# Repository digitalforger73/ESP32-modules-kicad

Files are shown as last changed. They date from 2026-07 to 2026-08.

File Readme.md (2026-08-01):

<h1 align="center">ESP32 Community Board Project</h1>

<p align="center">
A complete ESP32 reference design built with KiCad.
</p>

## Preview

### PCB

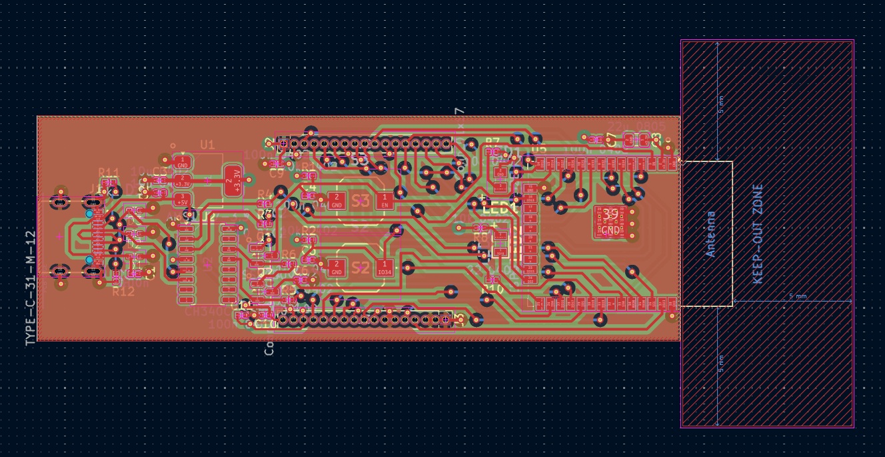
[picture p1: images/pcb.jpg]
ESP32 PCB


### Schematic

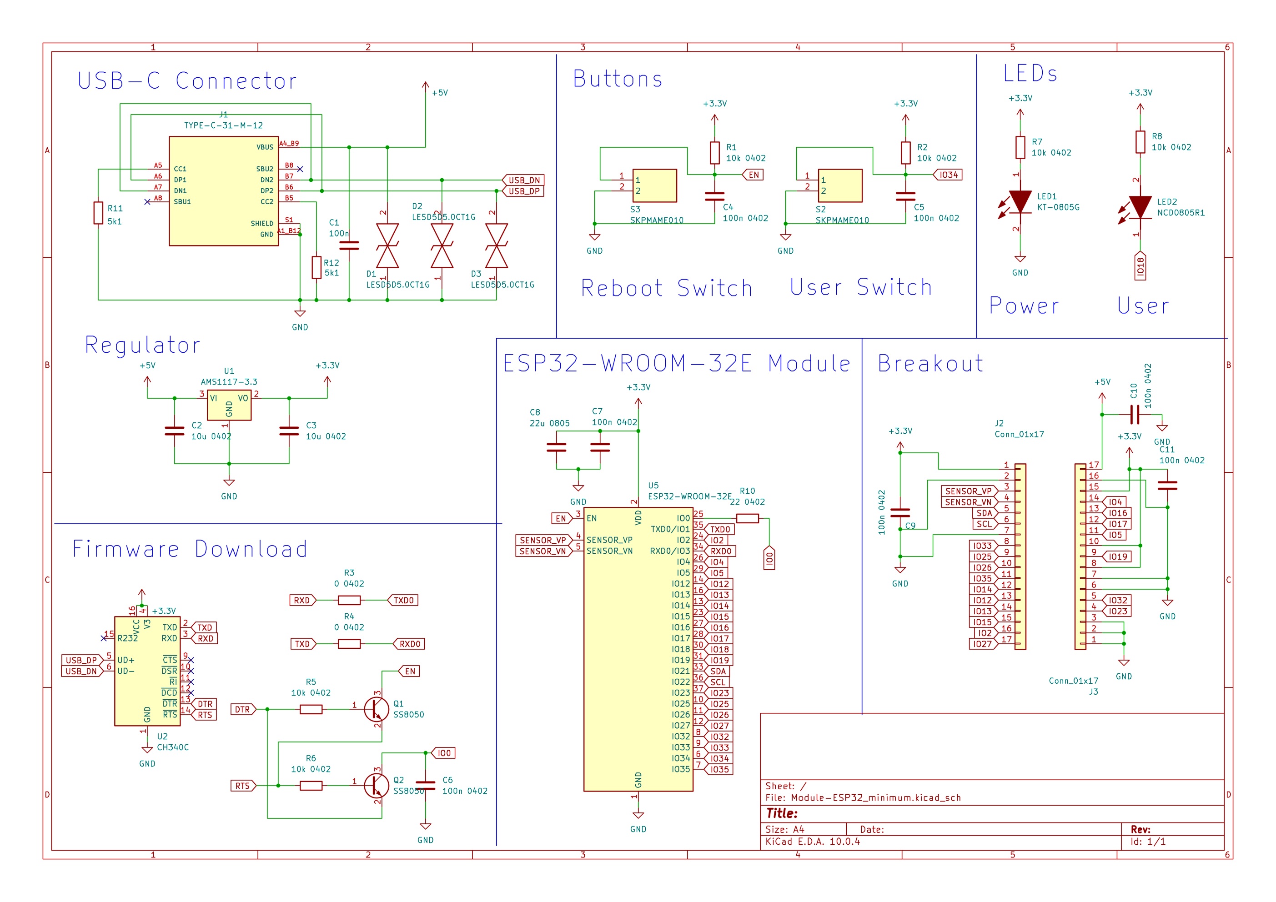
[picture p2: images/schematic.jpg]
ESP32 Schematic


An open community project for learning ESP32 hardware design with KiCad.

This repository contains a complete ESP32 development board designed in KiCad, intended for makers, students, and engineers who want to learn custom PCB design and build their own ESP32-based hardware.

<br>

## Professional Version - ESP32 Sensor Board

Need an ESP32 board with integrated sensors?

The **ESP32 Sensor Board** extends the Community Edition with a complete environmental sensing platform, making it suitable for IoT development, plant monitoring, and custom hardware projects.

### Professional Edition Includes

* SHTC3 temperature and humidity sensor
* Ambient light sensor
* Capacitive soil moisture sensor connector
* Complete KiCad project
* Schematic and PCB layout
* Symbol & footprint libraries
* BOM and Gerber files
* Component replacement guide
* Documentation

👉 **Professional Version on Gumroad**

[https://greentam.gumroad.com/](https://greentam.gumroad.com/?utm_source=github&utm_medium=readme&utm_campaign=community)

If you're looking for a solid starting point for your next ESP32 hardware project, the Professional Edition is designed to save development time while remaining fully customizable.

<br>

## Features

- ESP32-WROOM-32E
- USB Serial (CH340)
- 3.3V Power Regulator
- Reset / User Buttons
- A status LED / A user LED
- Programming Circuit
- Expansion Headers
- Symbols and Footprints on Components
- Component Replacement Guide

The project file contains the 4-layer substrate layout (front signal, 3.3 volt plane, ground plane, and back signal), and satisfies the pcb specification of the manufacturer, JLCPCB. 
You can give an order by uploading the gerber files, placement file, and bill-of-materials generated by the project files.
However, you can edit the files to match the specification of your chosen manufacturer.

<br>

## Who is this project for?

- ESP32 beginners
- Electronics hobbyists
- PCB designers
- Students
- Engineers learning KiCad
- Makers who want to build their own ESP32 board

<br>

## Community Edition

This repository contains the **Community Edition**.

The goal is to provide a minimal but practical ESP32 reference design that anyone can study and build.

<br>

## Documentation

- Component Replacement Guide
- Assembly Guide
- Hardware Documentation

<br>

## License

This project is licensed under the **Ippeul Community Hardware License (ICHL)**.

See the LICENSE file for details.

<br>

## Support

If you find this project useful, please consider:

- ⭐ Starring this repository
- Sharing it with other makers

<br><br>

<h1 align="center">KiCad를 이용한 ESP32 하드웨어 설계를 위한 ESP32 커뮤니티 보드</h1>

<p align="center">
KiCad로 디자인한 기본 ESP32 보드
</p>

<br>

이 저장소는 KiCad로 설계된 완전한 ESP32 개발 보드 프로젝트를 포함하고 있으며, 커스텀 PCB 설계를 배우고 자신만의 ESP32 기반 하드웨어를 제작하려는 메이커, 학생, 엔지니어를 위해 제작되었습니다.

<br>

## ESP32 센서 보드 (유료 버전)

센서가 통합된 ESP32 보드를 찾고 계신가요?

**ESP32 Sensor Board**는 Community Edition을 기반으로 온도·습도, 조도, 토양 수분 센서를 지원하도록 확장된 전문 KiCad 프로젝트입니다. IoT 기기, 식물 관리 시스템, 환경 모니터링 장치 등 다양한 하드웨어 개발에 바로 활용할 수 있습니다.

### ESP32 Sensor 구성

* SHTC3 온도·습도 센서
* 조도 센서
* 정전용량식 토양 수분 센서 연결 헤더
* 완전한 KiCad 프로젝트
* 회로도 및 PCB 설계
* 심볼 및 풋프린트 라이브러리
* BOM 및 Gerber 파일
* 부품 교체 가이드
* 프로젝트 문서

👉 Gumroad에서 다운로드:

[https://greentam.gumroad.com/](https://greentam.gumroad.com/?utm_source=github&utm_medium=readme&utm_campaign=community)

다음 ESP32 하드웨어 프로젝트를 보다 빠르게 시작하고 싶다면, ESP32 센서 보드는 검증된 회로와 PCB 설계를 바탕으로 개발 시간을 줄이면서도 자유롭게 수정하고 확장할 수 있는 기반을 제공합니다.

<br>

## ESP32 커뮤니티 보드 주요 기능 및 안내서
- ESP32-WROOM-32E
- USB 시리얼 인터페이스 (CH340)
- 3.3V 전압 레귤레이터
- Reset 버튼 / User 버튼
- 상태 표시 LED / 사용자 LED
- 펌웨어 다운로드 회로
- GPIO 확장 헤더
- 사용자 정의 심볼(Symbol) 및 풋프린트(Footprint)
- 대체 부품 가이드(Component Replacement Guide)

프로젝트 파일에는 4층 기판 구조가 포함되어 있습니다. 각 층은 전면 신호층, 3.3V 전원층, 접지층, 후면 신호층으로 구성되어 있으며, PCB 제조업체인 JLCPCB의 제작 사양을 충족합니다.
거버 파일, 부품 배치 파일, BOM(Bill of Materials)을 생성하고 업로드하여 바로 제작을 주문할 수 있습니다.
다만 선택한 PCB 제조업체의 제작 사양에 맞게 프로젝트 파일을 수정하여 사용할 수도 있습니다.

<br>

## 이 프로젝트는 누구를 위한 것인가요?
- ESP32를 처음 배우는 개발자
- 전자공학 취미 활동가
- PCB 설계자
- 학생
- KiCad를 배우는 엔지니어
- 자신만의 ESP32 보드를 제작하고 싶은 메이커

<br>

## 커뮤니티 버전
이 저장소에는 Community Edition이 포함되어 있습니다.

이 프로젝트의 목표는 누구나 학습하고 직접 제작할 수 있는 최소한의 기능을 갖춘 실용적인 ESP32 레퍼런스 디자인을 제공하는 것입니다.

<br>

## 라이선스
이 프로젝트는 Ippeul Community Hardware License (ICHL)에 따라 배포됩니다.
자세한 내용은 LICENSE 파일을 참고하시기 바랍니다.

<br>

## 서포트
프로젝트가 도움이 되었다면

이 프로젝트가 도움이 되었다면 다음과 같은 방법으로 응원해 주세요.

<br>

- ⭐ GitHub 저장소에 Star를 눌러 주세요.
- 다른 메이커와 개발자들에게 프로젝트를 공유해 주세요.

<br><br>

# ESP32 PCB 설계와 제작법을 제대로 배우고 싶다면

## KiCad로 만드는 나만의 센서 보드

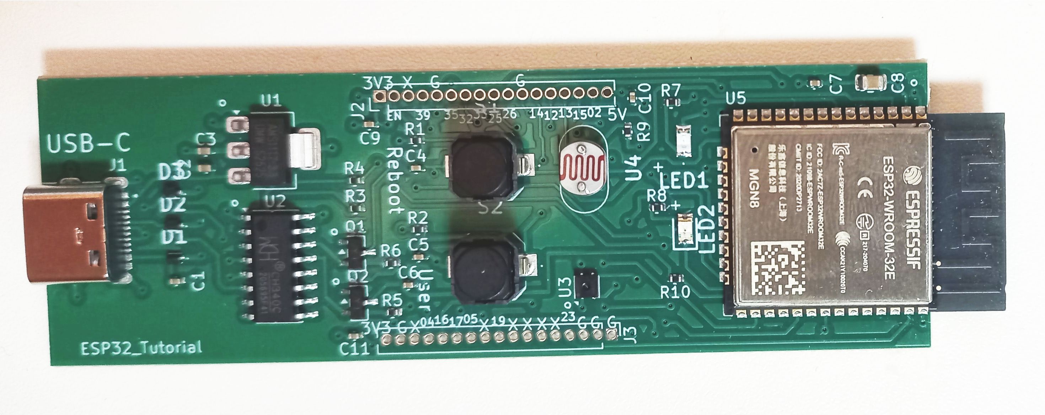
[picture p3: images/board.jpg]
ESP32 BOARD

(강의에서 제작하는 pcb)
<br>

ESP32 개발보드와 센서 모듈을 점퍼선으로 연결하는 데는 익숙하지만, 나만의 PCB를 설계하는 것은 막막하게 느껴질 수 있습니다.
<br>

이 강의에서는 실제 ESP32 센서 보드 프로젝트를 예제로 사용하여 다음 과정을 단계별로 배웁니다.
<br>

- ESP32 기본 회로 이해
- USB-C 전원 및 3.3V 전원 회로 설계
- CH340 기반 펌웨어 다운로드 회로
- 센서와 버튼·LED 연결
- KiCad 회로도 및 PCB 설계
- PCB 제조 파일 생성 및 주문
- ESP32 펌웨어 작성
- BLE와 Wi-Fi 통신 구현
<br>

강의를 마치면 개발보드를 사용하는 수준을 넘어, 원하는 기능을 갖춘 ESP32 PCB를 이해하고 직접 수정하거나 설계할 수 있습니다.
<br>

## 이런 분께 추천합니다
- ESP32 개발보드는 사용해봤지만 PCB 설계는 처음인 분
- KiCad를 실제 프로젝트를 통해 배우고 싶은 분
- 센서 기반 IoT 기기나 교육용 보드를 만들고 싶은 메이커
- 하드웨어와 펌웨어를 함께 이해하고 싶은 개발자
- 자신만의 IoT 시제품을 만들고 싶은 예비 창업자
<br>

강의에서는 수정 가능한 KiCad 프로젝트와 단계별 펌웨어를 함께 제공하여, 이후 다양한 ESP32 기반 프로젝트의 출발점으로 활용할 수 있습니다.
<br>

개발보드를 사용하는 사람에서, 자신의 보드를 설계하는 사람으로 한 단계 성장해 보세요.
<br>

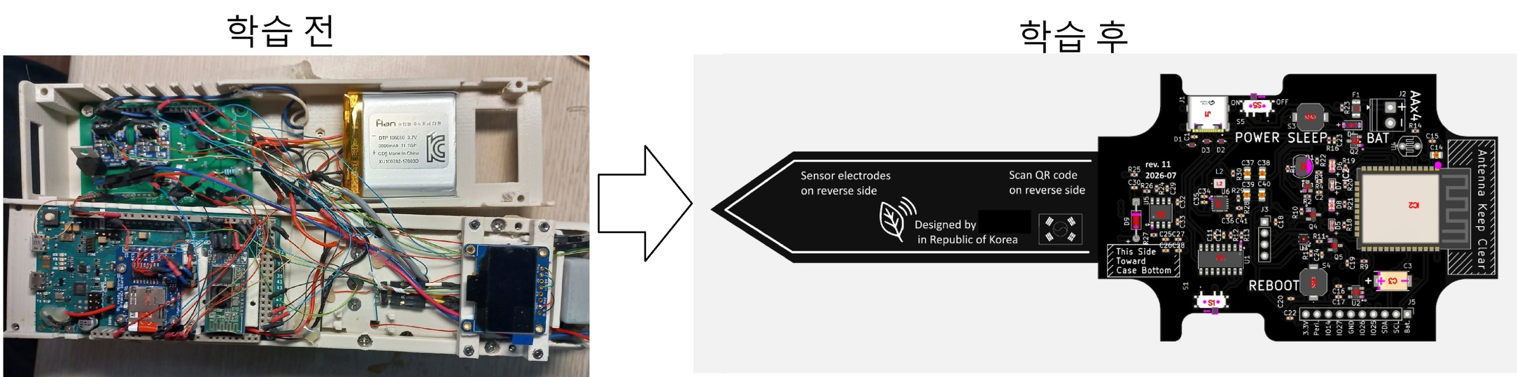
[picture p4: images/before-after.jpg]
ESP32 BEFORE_AFTER

(좌: 아두이노와 센서들이 각종 배선으로 연결된 시스템, 우: 센서와 ESP32가 일체화된 정돈된 커스텀 pcb)
<br>

## 강의 링크
https://inf.run/ZeYXg

<br>

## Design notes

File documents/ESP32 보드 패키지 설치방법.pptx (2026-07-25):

## ESP32 보드 패키지 설치방법

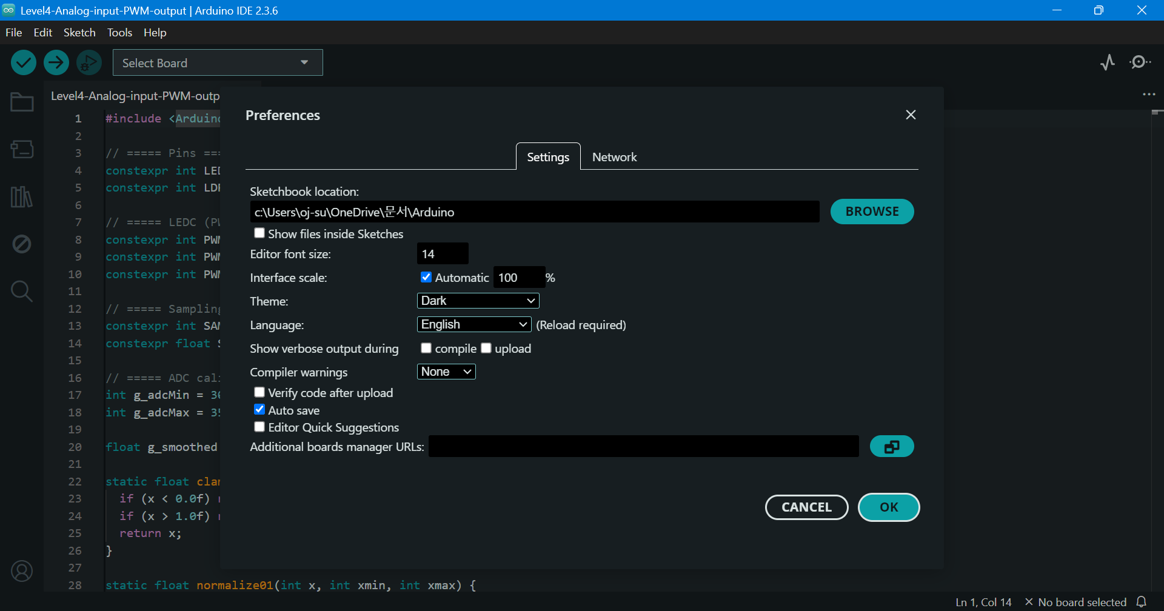
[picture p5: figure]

https://dl.espressif.com/dl/package_esp32_index.json

File → Preferences

## ESP32 보드 패키지 설치방법

Tools → Board → Boards Manager

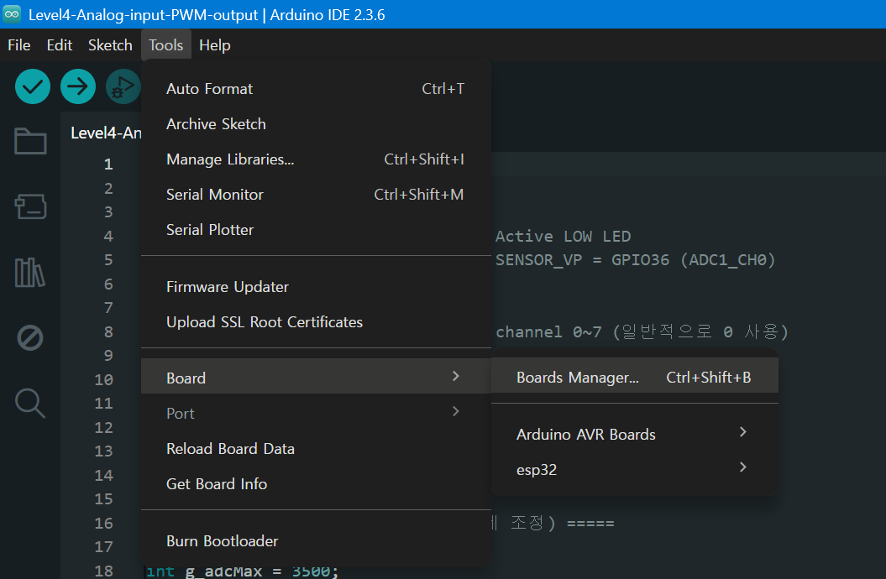
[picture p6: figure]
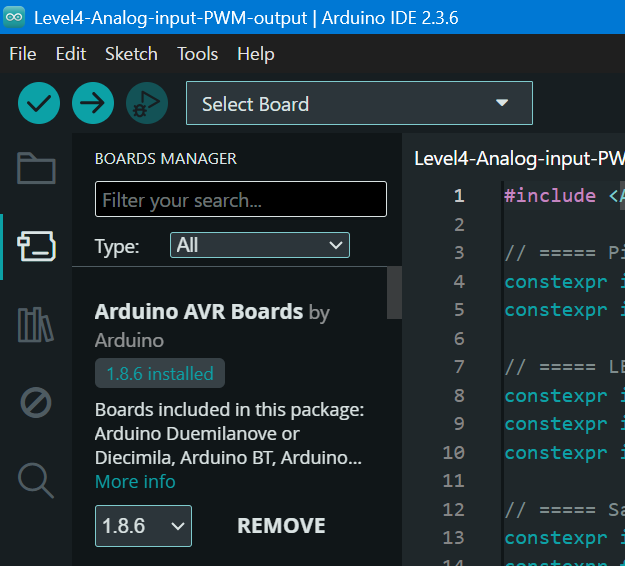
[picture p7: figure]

검색창에 ESP32입력

## ESP32 보드 패키지 설치방법

다음 항목 선택:
ESP32 by Espressif Systems
✔ Install 클릭

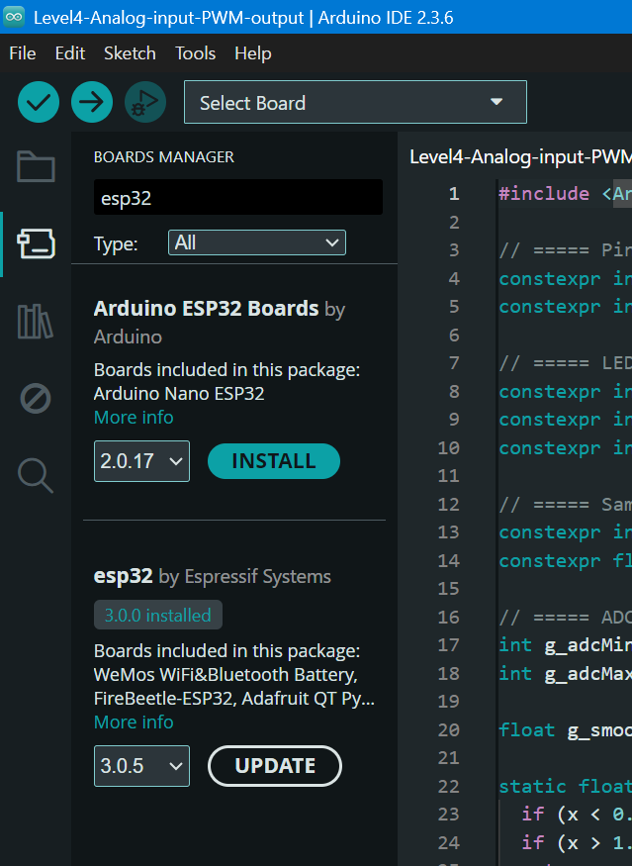
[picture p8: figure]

## ESP32 보드 패키지 설치방법

Tools → Board → ESP32-WROOM DA Module

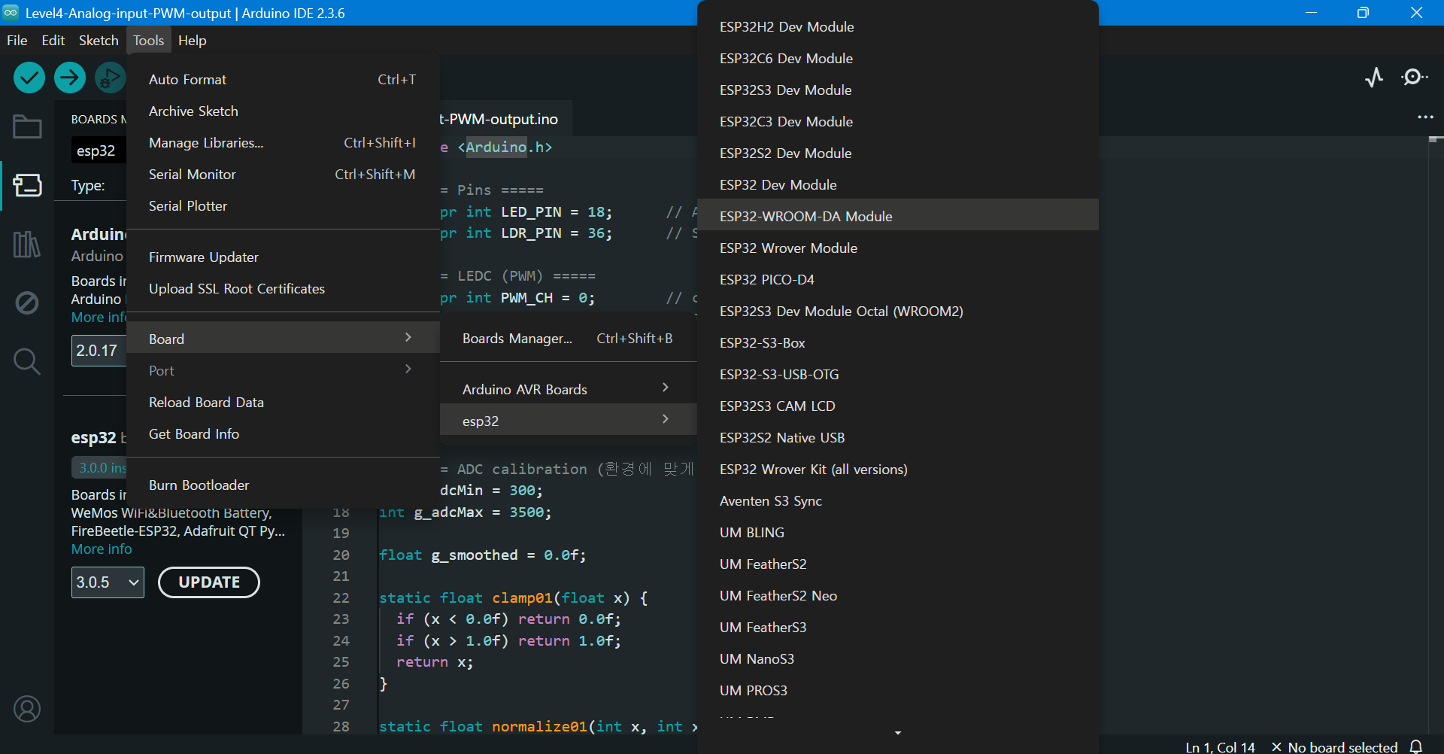
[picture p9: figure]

## ESP32 보드 패키지 설치방법

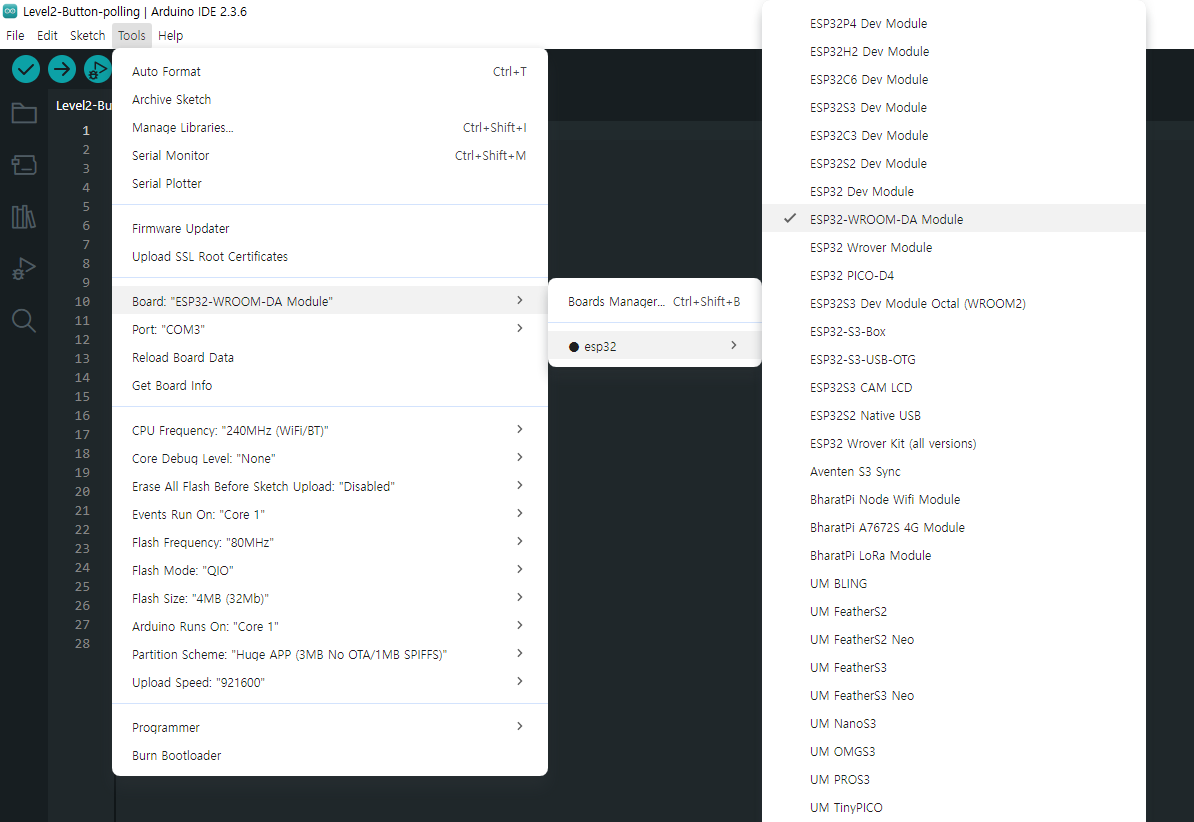
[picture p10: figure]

제작한 보드와 PC를 USB 케이블로 연결 후
Tools → Board

## ESP32 보드 패키지 설치방법

Tools → Port

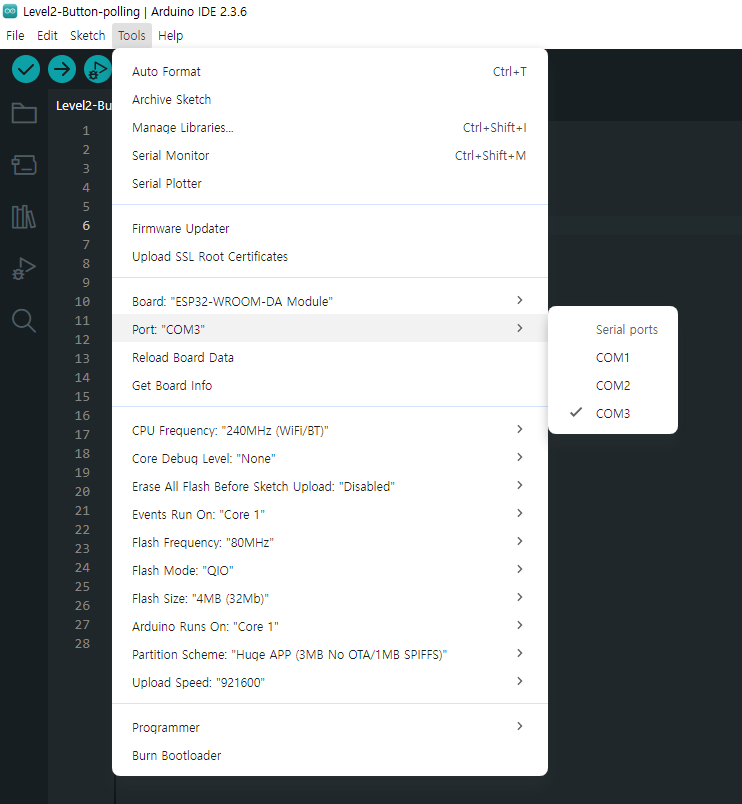
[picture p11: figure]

## ESP32 보드 패키지 설치방법

File → Examples

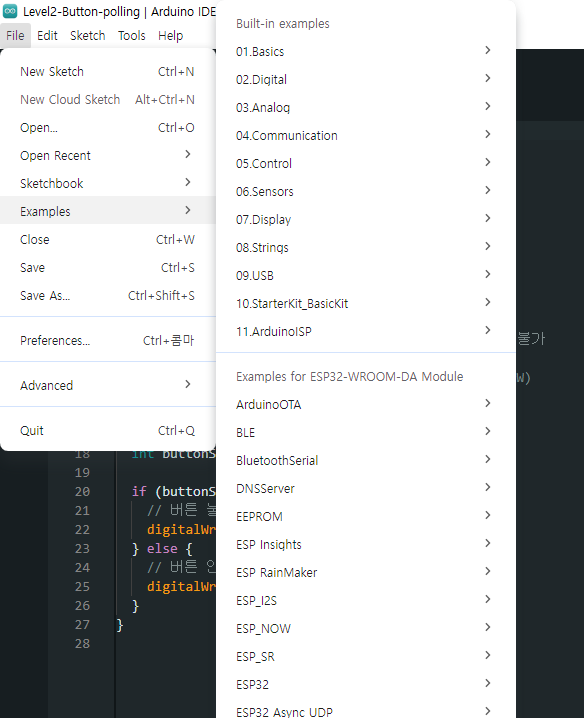
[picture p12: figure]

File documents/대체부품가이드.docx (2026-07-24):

대체 부품 가이드

이 문서는 프로젝트에 사용된 부품이 품절되었거나 다른 제조사의 부품으로 변경해야 할 때, KiCad 프로젝트에서 부품을 안전하게 교체하는 방법을 설명합니다.

부품을 교체할 때는 부품의 이름이나 외형만 확인해서는 안 됩니다. 전기적 특성, 핀 배열, 패키지 크기, 풋프린트, 정격 전압과 전류 등을 함께 확인해야 합니다.

특히 USB Type-C 커넥터, 스위치, 레귤레이터, USB-UART IC처럼 제조사마다 핀 배열과 외형이 다른 부품은 데이터시트를 반드시 확인해야 합니다.

1. 부품 교체 전 확인할 사항

부품을 교체하기 전에 다음 항목을 확인합니다.

전기적 특성

• 동작 전압
• 최대 입력 전압
• 출력 전압
• 허용 전류
• 소비전류
• 신호 속도
• 극성
• 보호 기능

핀 배열

같은 기능을 가진 부품이라도 핀 번호와 핀 위치가 다를 수 있습니다.

예를 들어 3.3V 레귤레이터라고 해도 다음 핀의 순서가 제조사와 패키지에 따라 달라질 수 있습니다.

• Input
• Ground
• Output
• Enable

기존 심벌을 그대로 사용하기 전에 새 부품의 데이터시트와 KiCad 심벌의 핀 번호가 일치하는지 확인해야 합니다.

패키지와 풋프린트

다음 항목을 확인합니다.

• SMD 또는 Through-hole 여부
• 패키지 형식
• 본체 크기
• 패드 간격
• 핀 수
• 핀 번호 방향
• 실장 높이
• 권장 Land Pattern

부품의 패키지 이름이 같더라도 제조사에 따라 권장 패드 크기가 다를 수 있습니다.

정격

새 부품의 정격은 기존 부품과 같거나 더 높아야 합니다.

예를 들어 기존 캐패시터가 10μF, 10V라면 교체 부품도 최소 10μF, 10V 이상을 사용하는 것이 좋습니다.

2. KiCad에서 부품을 교체하는 기본 절차
1. 새 부품의 데이터시트를 준비합니다.
2. 기존 부품과 새 부품의 전기적 특성을 비교합니다.
3. 새 부품의 핀 배열을 확인합니다.
4. KiCad 기본 라이브러리에 해당 심벌과 풋프린트가 있는지 확인합니다.
5. 적합한 심벌이 없다면 새 심벌을 만듭니다.
6. 적합한 풋프린트가 없다면 새 풋프린트를 만듭니다.
7. 회로도에서 기존 부품의 심벌 또는 부품 속성을 변경합니다.
8. 새 심벌의 핀 번호와 회로 연결을 확인합니다.
9. PCB Editor에서 회로도 변경 사항을 업데이트합니다.
10. 기존 풋프린트와 새 풋프린트의 위치 및 방향을 확인합니다.
11. PCB 배선을 수정합니다.
12. ERC와 DRC를 실행합니다.
13. 3D Viewer에서 부품의 방향과 간섭 여부를 확인합니다.
14. 제작 전 Gerber 파일과 조립 파일을 최종 검토합니다.
3. USB Type-C 커넥터 교체

기본 부품

TYPE-C-31-M-12

교체 가능한 부품

• HRO TYPE-C-31-M-12
• GCT USB Type-C 커넥터
• Amphenol USB Type-C 커넥터
• 다른 제조사의 USB 2.0 Type-C 커넥터

4. USB-UART IC 교체

기본 부품

CH340C

교체 가능한 부품

• CH340N
• CH9102F
• CP2102N
• FT231X
• 다른 USB-UART Bridge IC

5. 3.3V 레귤레이터 교체

기본 부품

AMS1117-3.3

교체 가능한 부품

• AP2112K-3.3
• ME6211-3.3
• TLV75533
• XC6206P332
• HT7333
• 다른 3.3V LDO

6. ESD 보호 다이오드 교체

기본 부품

LESD5D5.0CT1G

교체 가능한 부품

• PESD5V 계열
• USBLC6 계열
• TPD 계열 USB 보호 소자
• 다른 Low-Capacitance TVS Diode

7. 택트 스위치 교체

기본 부품

SKPMAME010

교체 가능한 부품

• 다른 제조사의 SMD Tact Switch
• C&K Tact Switch
• Omron Tact Switch
• ALPS Alpine Tact Switch
• 동일 크기의 범용 4핀 스위치

8. LED 교체

기본 부품

• KT-0805G
• NCD0805R1

교체 가능한 부품

• 다른 제조사의 0805 LED
• 0603 LED
• 1206 LED
• 다른 색상의 LED

9. 저항 교체

기본 패키지

0402

교체 가능한 패키지

• 0603
• 0805
• 1206

10. 캐패시터 교체

확인할 사항

• 정전용량
• 정격 전압
• 유전체 종류
• 허용 오차
• DC Bias 특성
• ESR
• 패키지 크기

세라믹 캐패시터는 인가 전압에 따라 실제 정전용량이 크게 감소할 수 있습니다.

특히 작은 패키지의 고용량 캐패시터는 DC Bias 영향이 클 수 있습니다.

예를 들어 0402 크기의 10μF 캐패시터는 3.3V 또는 5V가 인가되었을 때 실제 정전용량이 표기값보다 크게 낮아질 수 있습니다.

따라서 레귤레이터의 안정성이나 ESP32 전원 안정화가 중요하다면 0603 또는 0805 패키지를 검토하는 것이 좋습니다.

11. ESP32 모듈 교체

기본 부품

ESP32-WROOM-32E

교체 가능한 부품

• ESP32-WROOM-32D
• ESP32-WROOM-32UE
• ESP32-WROVER 계열
• ESP32-S3-WROOM 계열
• ESP32-C3-WROOM 계열

확인할 사항

같은 ESP32 계열이라도 모듈마다 다음 사항이 다를 수 있습니다.

• 모듈 크기
• 핀 수
• 핀 배열
• 안테나 방식
• Flash 용량
• PSRAM 유무
• 전원 요구사항
• USB 기능
• 부팅 핀
• 사용 가능한 GPIO
• 입력 전용 GPIO
• ADC 특성

ESP32-WROOM-32D와 ESP32-WROOM-32E는 비교적 유사하지만, ESP32-S3나 ESP32-C3로 변경할 경우에는 회로와 펌웨어를 상당 부분 수정해야 합니다.

12. 커넥터 교체

기본 부품

Conn_01x17

교체 가능한 부품

• 2.54mm Pin Header
• 2.00mm Pin Header
• JST 계열 커넥터
• Board-to-Board Connector
• Screw Terminal

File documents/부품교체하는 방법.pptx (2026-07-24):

## 부품을 교체하기에 앞서

- 교체할 부품이 KiCad 라이브러리에 있는지 먼저 확인합니다.
- 없을 경우, 온라인으로 검색하여 찾은 후 라이브러리에 추가합니다.
- 부품 검색 엔진: www.componentsearchengine.com
- 추가하는 방법은 유튜브 등을 참고하세요
- https://www.youtube.com/watch?v=7qVhKbithF0&t=1237s

## 1. 부품 추가하기

- 오른쪽 아이콘을 누르거나 단축키 ‘A’키를 눌러서 부품 추가하기

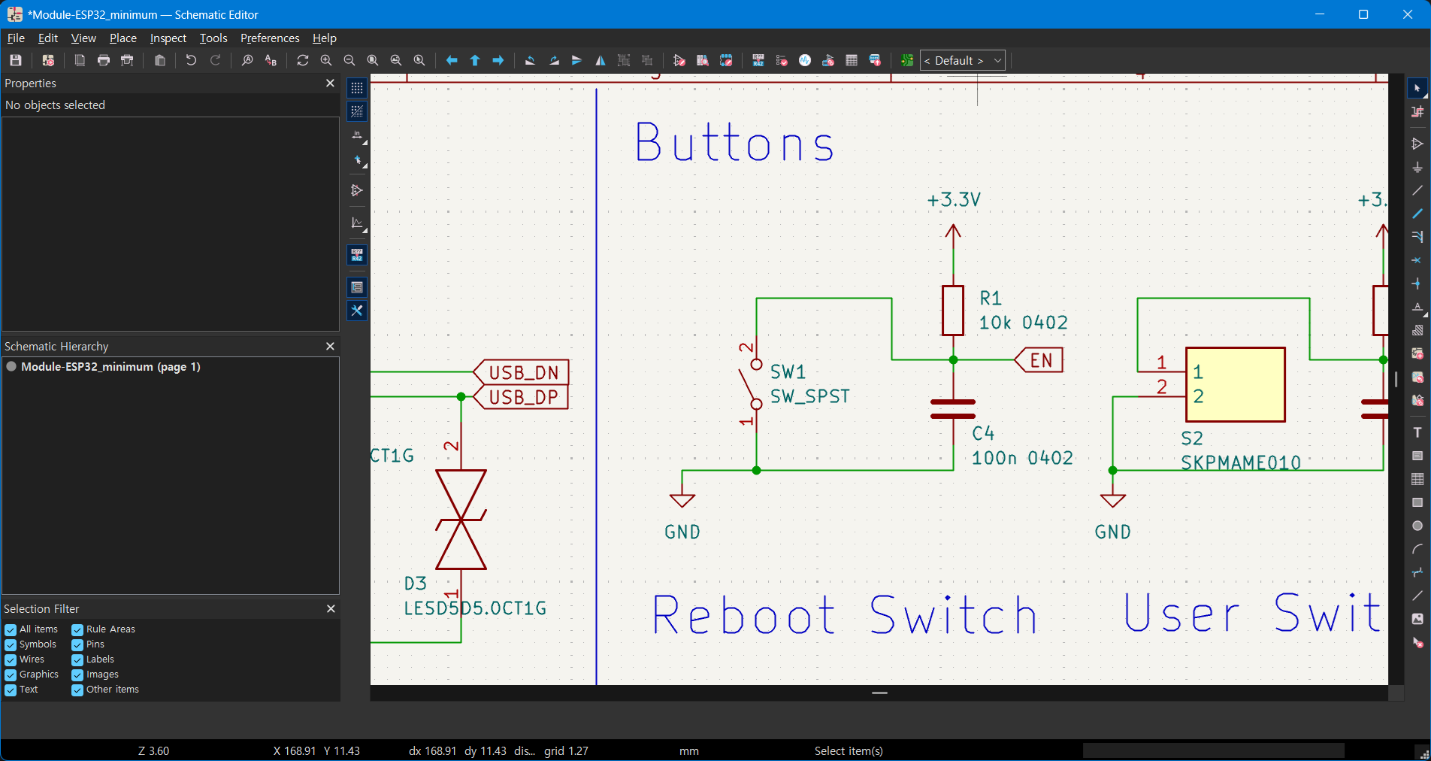
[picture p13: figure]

대체할 부품 심볼

## 2. 심볼 라이브러리에서 부품 찾기

- 라이브러리 필터에 이름을 입력(예: SKPMAME010) 후, OK

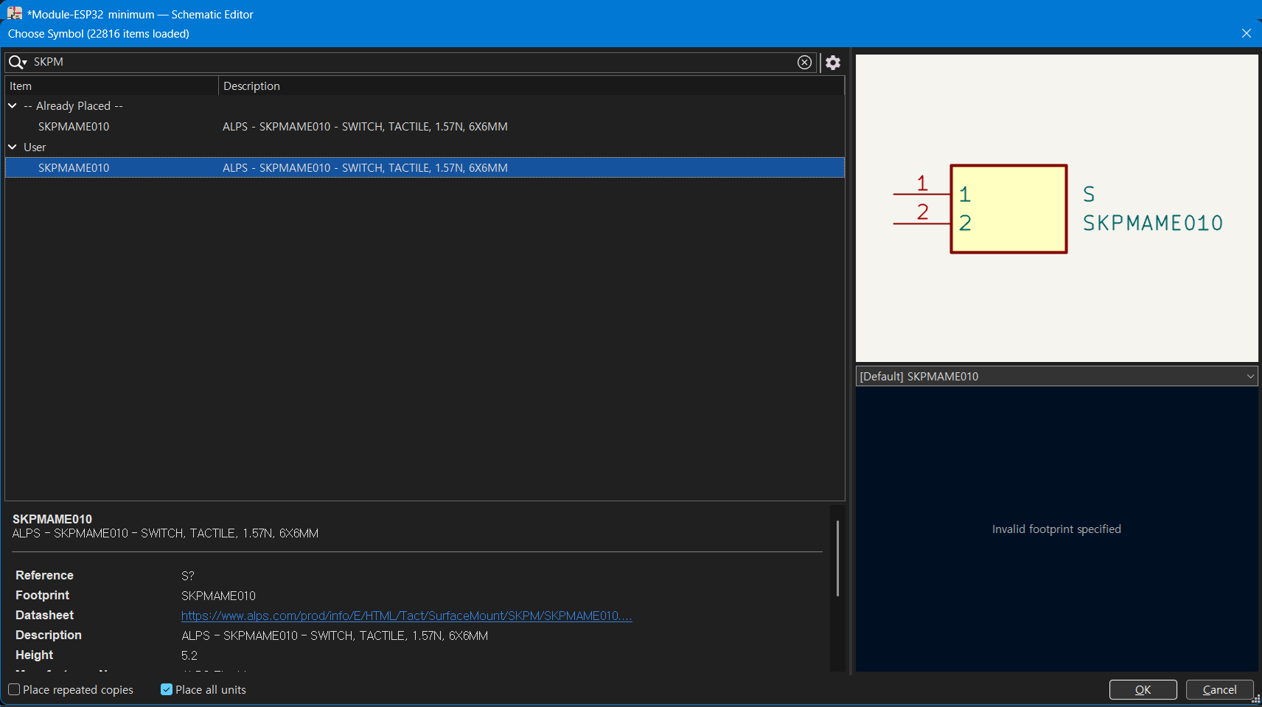
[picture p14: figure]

## 3. 심볼 변경하기

- 기존의 심볼을 지운 후, 추가한 심볼을 그자리에 넣고 선 연결

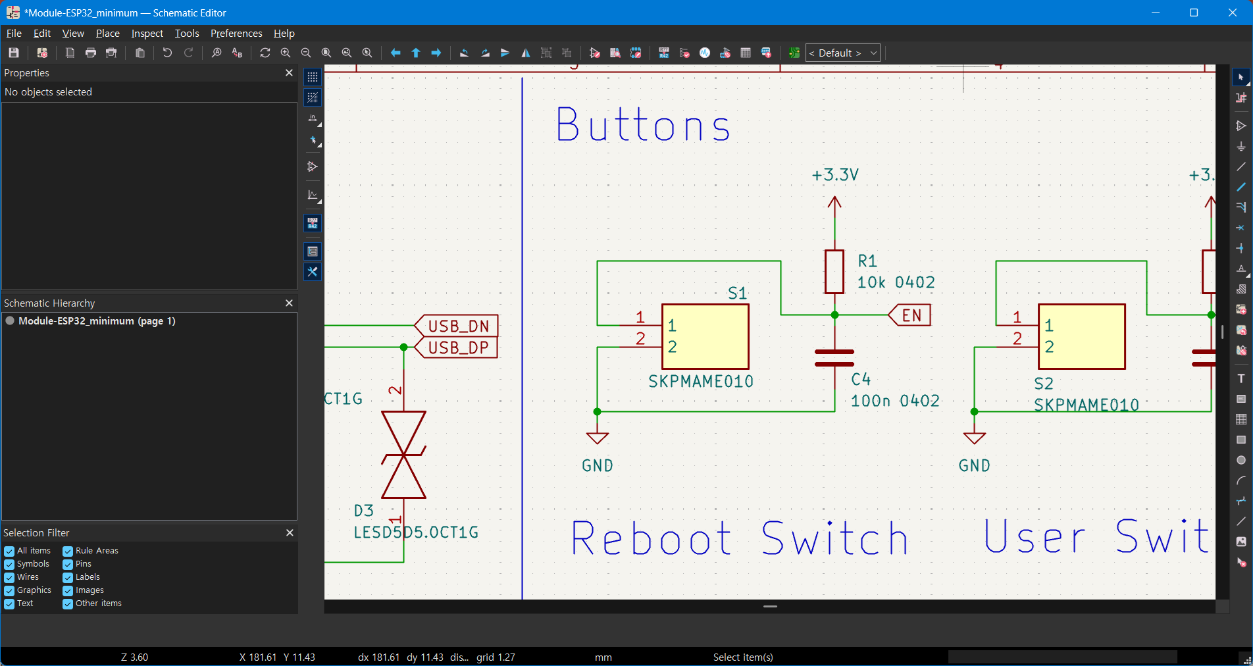
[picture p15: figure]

추가된 부품 심볼

## 4. PCB 편집기 창으로 이동

- ‘PCB 편집기로 이동’ 아이콘을 클릭하여 이동

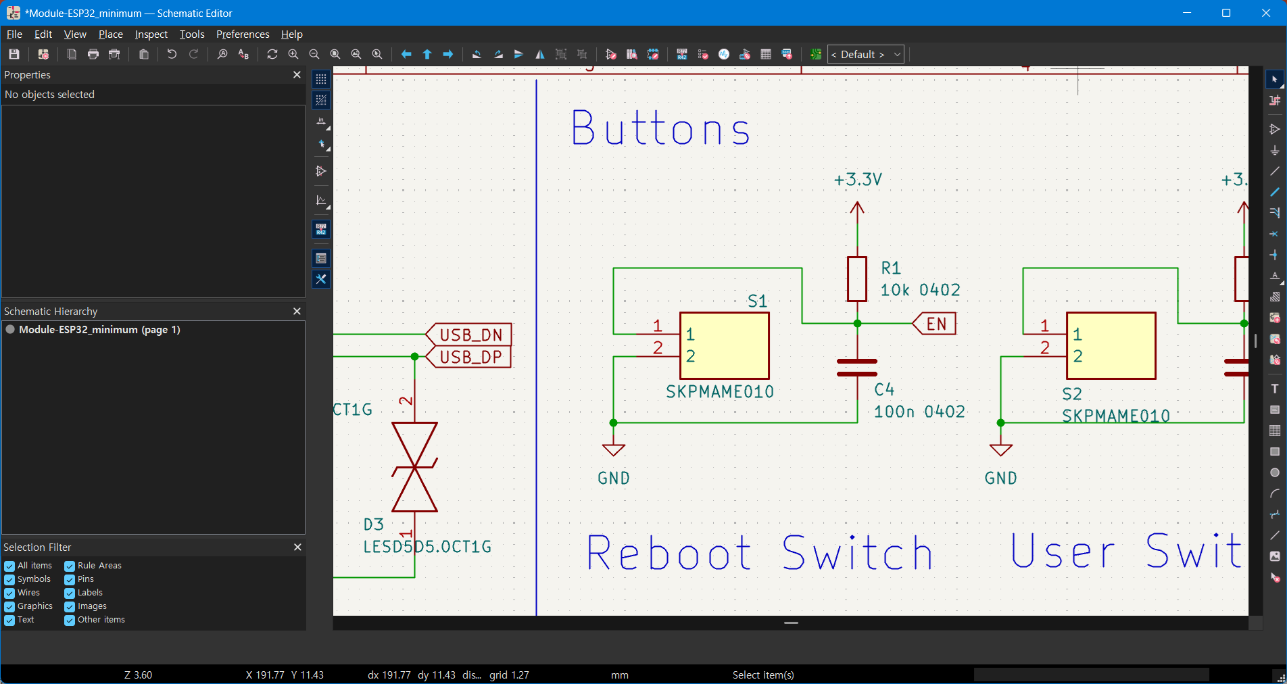
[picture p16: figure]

## 5. PCB 업데이트하기

- ‘Schematic으로부터 PCB 업데이트’하기 아이콘 누르기

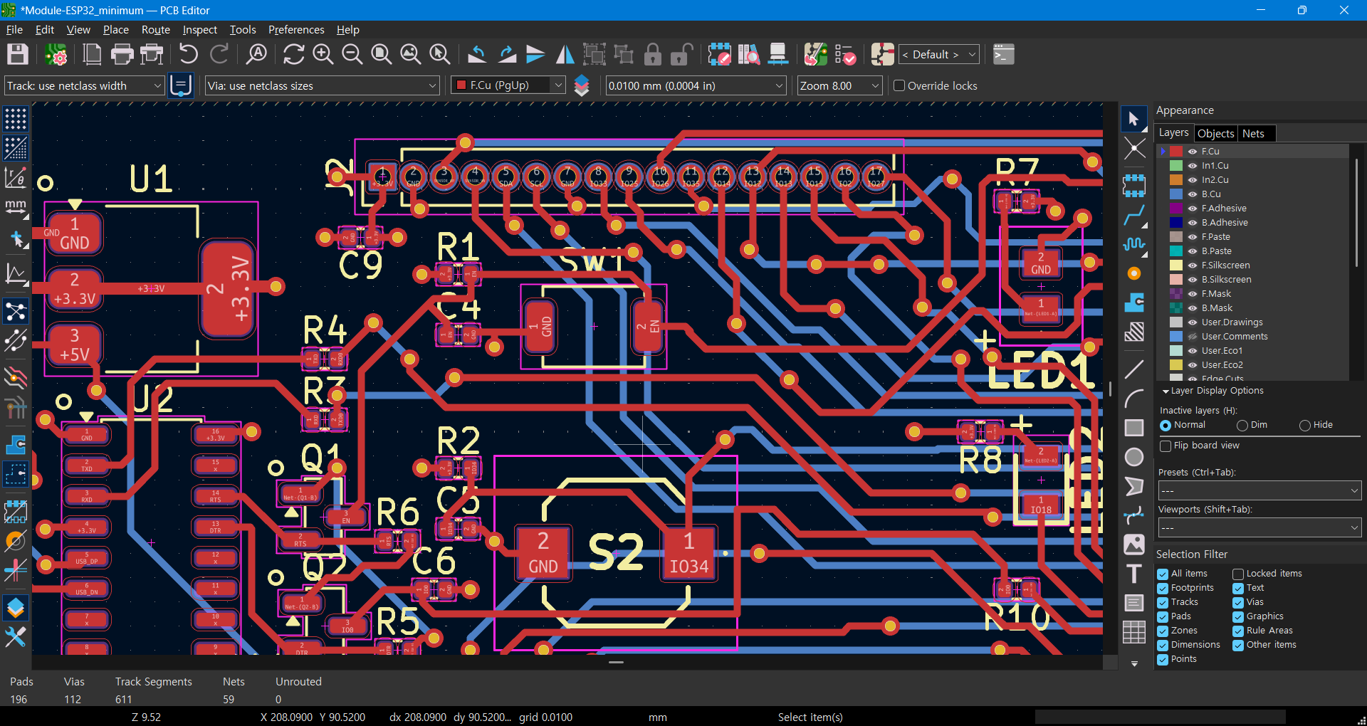
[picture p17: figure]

대체할 부품 심볼

## 6. 추가된 부품 놓기

- 새로 추가된 부품의 Footprint를 원하는 위치에 놓기

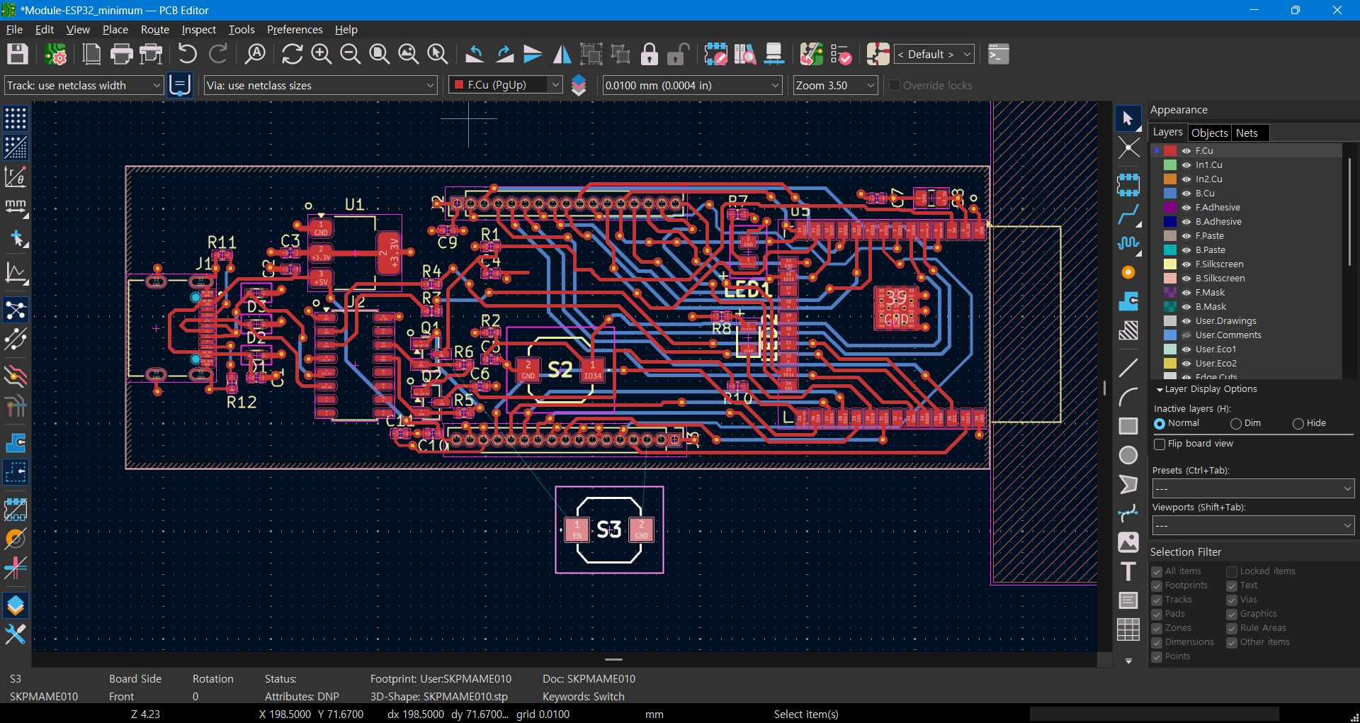
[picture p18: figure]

## 7. 배선 재 연결

- 추가된 부품의 끊어진 배선을 다시 연결

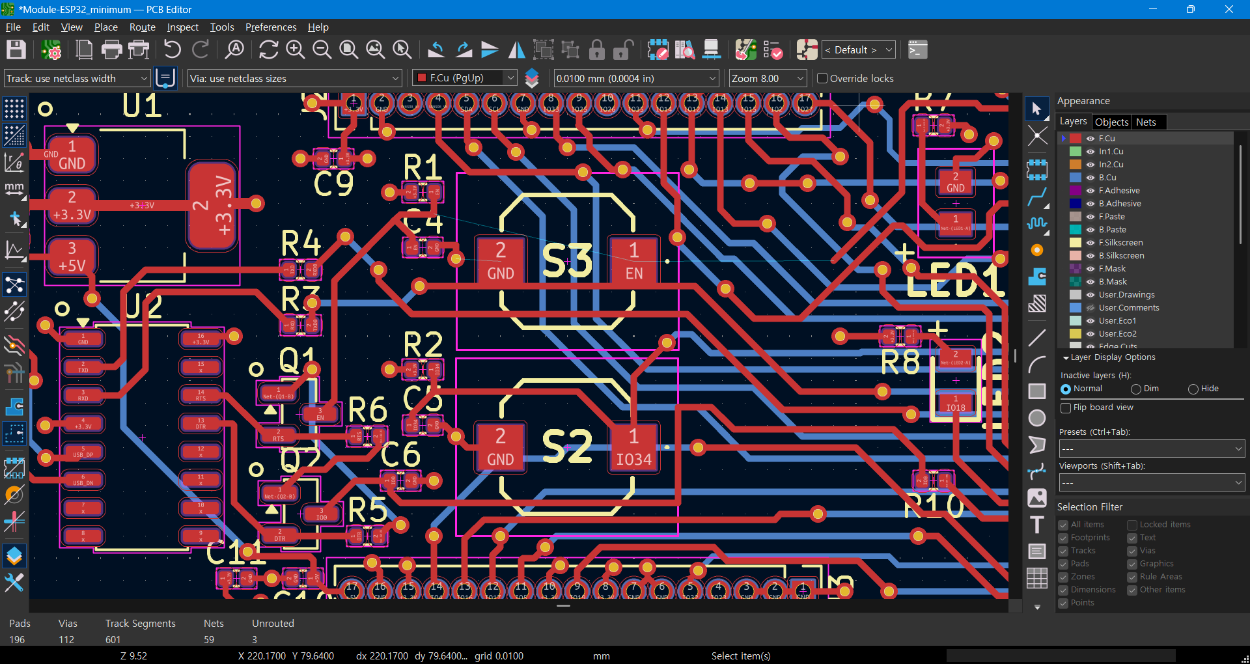
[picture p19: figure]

## 8. 주변 선 정리

- 추가된 부품과 기존 배선의 충돌을 방지하기위해 주변 배선을 이동함

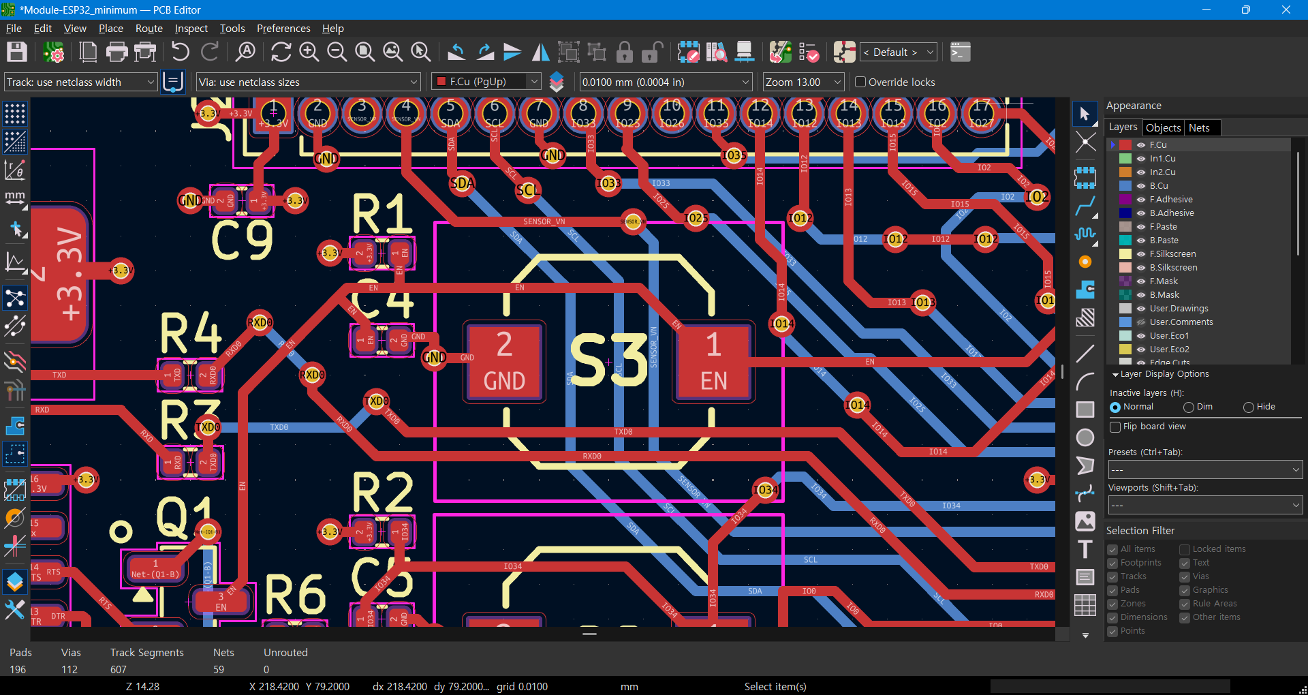
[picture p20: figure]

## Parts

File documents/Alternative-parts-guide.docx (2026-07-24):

# Component Replacement Guide

This document explains how to safely replace components in the KiCad project when the original parts are out of stock or need to be substituted with equivalent components from other manufacturers.

When replacing a component, do not rely solely on its name or physical appearance. Always verify its electrical characteristics, pin configuration, package type, footprint, voltage and current ratings, and other critical specifications.

For components such as USB Type-C connectors, switches, voltage regulators, and USB-to-UART bridge ICs, the pin assignments and mechanical dimensions often vary between manufacturers. Therefore, always consult the component's datasheet before making a replacement.

## 1. Things to Check Before Replacing a Component

Before selecting a replacement component, verify the following items.

### Electrical Characteristics

- Operating voltage
- Maximum input voltage
- Output voltage
- Maximum current rating
- Current consumption
- Signal speed
- Polarity
- Protection features

### Pin Configuration

Even components with the same function may have different pin numbers or pin assignments.

For example, a 3.3 V voltage regulator may have different pin orders depending on the manufacturer or package type, such as:

- Input
- Ground
- Output
- Enable

Before reusing the existing KiCad symbol, verify that the pin numbers in the symbol match those specified in the datasheet of the replacement component.

### Package and Footprint

Check the following items:

- SMD or through-hole package
- Package type
- Body dimensions
- Pad spacing
- Number of pins
- Pin numbering orientation
- Mounting height
- Recommended land pattern

Even if two components share the same package name, the recommended PCB land pattern may differ between manufacturers.

### Electrical Ratings

The replacement component should have ratings that are equal to or greater than those of the original component.

## For example, if the original capacitor is rated at 10 μF, 10 V, the replacement should also be rated for at least 10 μF and 10 V, or higher. 2. Basic Procedure for Replacing a Component in KiCad

1. Obtain the datasheet for the replacement component.
2. Compare the electrical characteristics of the original and replacement components.
3. Verify the pin configuration of the replacement component.
4. Check whether a suitable symbol and footprint are available in the KiCad standard libraries.
5. If no suitable symbol exists, create a new symbol.
6. If no suitable footprint exists, create a new footprint.
7. Replace the symbol or update the component properties in the schematic.
8. Verify that the pin numbers and schematic connections match the new symbol.
9. Update the PCB layout from the modified schematic.
10. Verify the position and orientation of the new footprint.
11. Modify the PCB routing as required.
12. Run ERC (Electrical Rules Check) and DRC (Design Rules Check).
13. Use the 3D Viewer to verify the component orientation and check for mechanical interference.
14. Before manufacturing, perform a final review of the Gerber files and assembly files.

## 3. Replacing the USB Type-C Connector

Original Component

TYPE-C-31-M-12

Possible Replacements

- HRO TYPE-C-31-M-12
- GCT USB Type-C Connector
- Amphenol USB Type-C Connector
- USB 2.0 Type-C connectors from other manufacturers

## 4. Replacing the USB-to-UART Bridge IC

Original Component

CH340C

Possible Replacements

- CH340N
- CH9102F
- CP2102N
- FT231X
- Other USB-to-UART bridge ICs

## 5. Replacing the 3.3 V Voltage Regulator

Original Component

AMS1117-3.3

Possible Replacements

- AP2112K-3.3
- ME6211-3.3
- TLV75533
- XC6206P332
- HT7333
- Other 3.3 V LDO regulators

## 6. Replacing the ESD Protection Diode

Original Component

LESD5D5.0CT1G

Possible Replacements

- PESD5V series
- USBLC6 series
- TPD series USB protection devices
- Other low-capacitance TVS diodes

## 7. Replacing the Tactile Switch

Original Component

SKPMAME010

Possible Replacements

- SMD tactile switches from other manufacturers
- C&K tactile switches
- Omron tactile switches
- ALPS Alpine tactile switches
- Any standard 4-pin tactile switch with the same footprint

## 8. Replacing the LEDs

Original Components

- KT-0805G
- NCD0805R1

Possible Replacements

- 0805 LEDs from other manufacturers
- 0603 LEDs
- 1206 LEDs
- LEDs of different colors

## 9. Replacing Resistors

Original Package

0402

Compatible Package Options

- 0603
- 0805
- 1206

## 10. Replacing Capacitors

Items to Verify

- Capacitance
- Rated voltage
- Dielectric type
- Tolerance
- DC bias characteristics
- Equivalent Series Resistance (ESR)
- Package size

The effective capacitance of ceramic capacitors can decrease significantly as the applied DC voltage increases.

This effect is particularly noticeable in high-capacitance capacitors with small package sizes.

For example, a 10 μF capacitor in a 0402 package may provide considerably less than its nominal capacitance when operated at 3.3 V or 5 V.

If regulator stability or ESP32 power stability is important, consider using a 0603 or 0805 package instead.

## 11. Replacing the ESP32 Module

Original Component

ESP32-WROOM-32E

Possible Replacements

- ESP32-WROOM-32D
- ESP32-WROOM-32UE
- ESP32-WROVER series
- ESP32-S3-WROOM series
- ESP32-C3-WROOM series

Items to Verify

Even within the ESP32 family, different modules may vary in the following aspects:

- Module dimensions
- Number of pins
- Pin configuration
- Antenna type
- Flash memory capacity
- PSRAM availability
- Power requirements
- USB functionality
- Boot pins
- Available GPIO pins
- Input-only GPIO pins
- ADC characteristics

The ESP32-WROOM-32D and ESP32-WROOM-32E are largely compatible. However, migrating to an ESP32-S3 or ESP32-C3 typically requires significant modifications to both the hardware design and the firmware.

## 12. Replacing the Connectors

Original Component

Conn_01x17

Possible Replacements

- 2.54 mm Pin Header
- 2.00 mm Pin Header
- JST series connectors
- Board-to-Board connectors
- Screw terminals

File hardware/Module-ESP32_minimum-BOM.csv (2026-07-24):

Reference | Qty | Value | DNP | Exclude from BOM | Exclude from Board | Footprint | JLCPCB
C1,C4,C5,C6,C7,C9,C10,C11 | 8 | 100n 0402 |  |  |  | Capacitor_SMD:C_0402_1005Metric | C1525
C2,C3 | 2 | 10u 0402 |  |  |  | Capacitor_SMD:C_0402_1005Metric | C15525
C8 | 1 | 22u 0805 |  |  |  | Capacitor_SMD:C_0805_2012Metric | C5674
D1,D2,D3 | 3 | LESD5D5.0CT1G |  |  |  | LESD5D50CT1G | C5199850
J1 | 1 | TYPE-C-31-M-12 |  |  |  | User:HRO_TYPE-C-31-M-12 | C165948
J2,J3 | 2 | Conn_01x17 |  |  |  | Connector_PinHeader_1.27mm:PinHeader_1x17_P1.27mm_Vertical | X
LED1 | 1 | KT-0805G |  |  |  | KT0805G | C2297
LED2 | 1 | NCD0805R1 |  |  |  | LEDC2012X120N | C84256
Q1,Q2 | 2 | SS8050 |  |  |  | Package_TO_SOT_SMD:SOT-23 | C164886
R1,R2,R5,R6,R7,R8,R9 | 7 | 10k 0402 |  |  |  | Resistor_SMD:R_0402_1005Metric | C25744
R3,R4 | 2 | 0 0402 |  |  |  | Resistor_SMD:R_0402_1005Metric | C17168
R10 | 1 | 22 0402 |  |  |  | Resistor_SMD:R_0402_1005Metric | C25092
S1,S2 | 2 | SKPMAME010 |  |  |  | SKPMAME010 | C115348
U1 | 1 | AMS1117-3.3 |  |  |  | Package_TO_SOT_SMD:SOT-223-3_TabPin2 | C347222
U2 | 1 | CH340C |  |  |  | Package_SO:STC_SOP-16_3.9x9.9mm_P1.27mm | C84681
U3 | 1 | SHTC3 |  |  |  | Sensor_Humidity:Sensirion_DFN-4-1EP_2x2mm_P1mm_EP0.7x1.6mm | C2880044
U4 | 1 | GL5528 |  |  |  | GL5528 | C125627
U5 | 1 | ESP32-WROOM-32E |  |  |  | RF_Module:ESP32-WROOM-32D | C701342

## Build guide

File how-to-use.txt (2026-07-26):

This project is generated by KiCad version 10.

1. Install ESP board packages using "ESP32 Board Package Installation"

2. Create 'User' symbol library and 'User' footprint library in the KiCad.
(Typically at {user_home directory}/Document/KiCad/10.0/symbols and {user_home directory}/Document/KiCad/10.0/footprints)

3. Unzip all the files under components directory to a selected directory, and add their symbols and footprints to the created User libraries of KiCad. 

4. Open schematic editor window. If a part is missing, add the new part from the symbol library. Also, select the part and press 'E' key to open its properties window. Then at the footprint field, open the user footprint library and choose the new part's footprint in the user library.

5. Switch to the pcb editor window, and click 'Update the pcb from schematic' icon to update the pcb. Then reroute the new footprints.

6. Refer to "how-to-replace-a-part", if a part is missing or if you need to replace a part with your preferred one.

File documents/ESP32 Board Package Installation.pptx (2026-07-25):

## ESP32 Board Package Installation


https://dl.espressif.com/dl/package_esp32_index.json

File → Preferences

## ESP32 Board Package Installation

Tools → Board → Boards Manager


Search ‘ESP32’

## ESP32 Board Package Installation

Choose:
ESP32 by Espressif Systems
✔ and click ‘Install’


## ESP32 Board Package Installation

Tools → Board → ESP32-WROOM DA Module


## ESP32 Board Package Installation


After connecting the board and PC by a USB cable,
Tools → Board

## ESP32 Board Package Installation

Tools → Port


## ESP32 Board Package Installation

File → Examples


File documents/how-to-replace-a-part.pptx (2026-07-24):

## Before replacing a component,

- First check whether it is available in the KiCad library.
- If the component is not available, search for it online and add it to your KiCad library.
- Component Search Engine:
- www.componentsearchengine.com
- For instructions on adding downloaded libraries to KiCad, refer to the following YouTube tutorial:
- https://www.youtube.com/watch?v=7qVhKbithF0&t=1237s
- Component Search Engine provides free schematic symbols, PCB footprints, and 3D models for KiCad, making it a convenient resource when a required component is missing from the standard KiCad libraries.

## 1. Add a part

- Click the Add Symbol icon on the right toolbar, or simply press the A key to add a new component to the schematic.


대체할 부품 심볼

## 2. Find a part in the symbol library

- Enter the component name in the Library Filter field (for example, SKPMAME010), then click OK.


## 3. Replace the symbol

- Delete the existing symbol, then place the newly added symbol in the same location and reconnect the wires.


the new symbol

## 4. Go to PCB editor

- Move to PCB editor by clicking “Switch to PCB editor” icon.


## 5. Update PCB

- Click icon, “Update pcb from the schematic”


대체할 부품 심볼

## 6. Place the new footprint

- Place the new footprint by clicking the mouse button


## 7. Rewire

- Reconnect the wires to the new footprint


## 8. Arrange nearby paths

- Avoid conflict of existing wires with the new footprint.


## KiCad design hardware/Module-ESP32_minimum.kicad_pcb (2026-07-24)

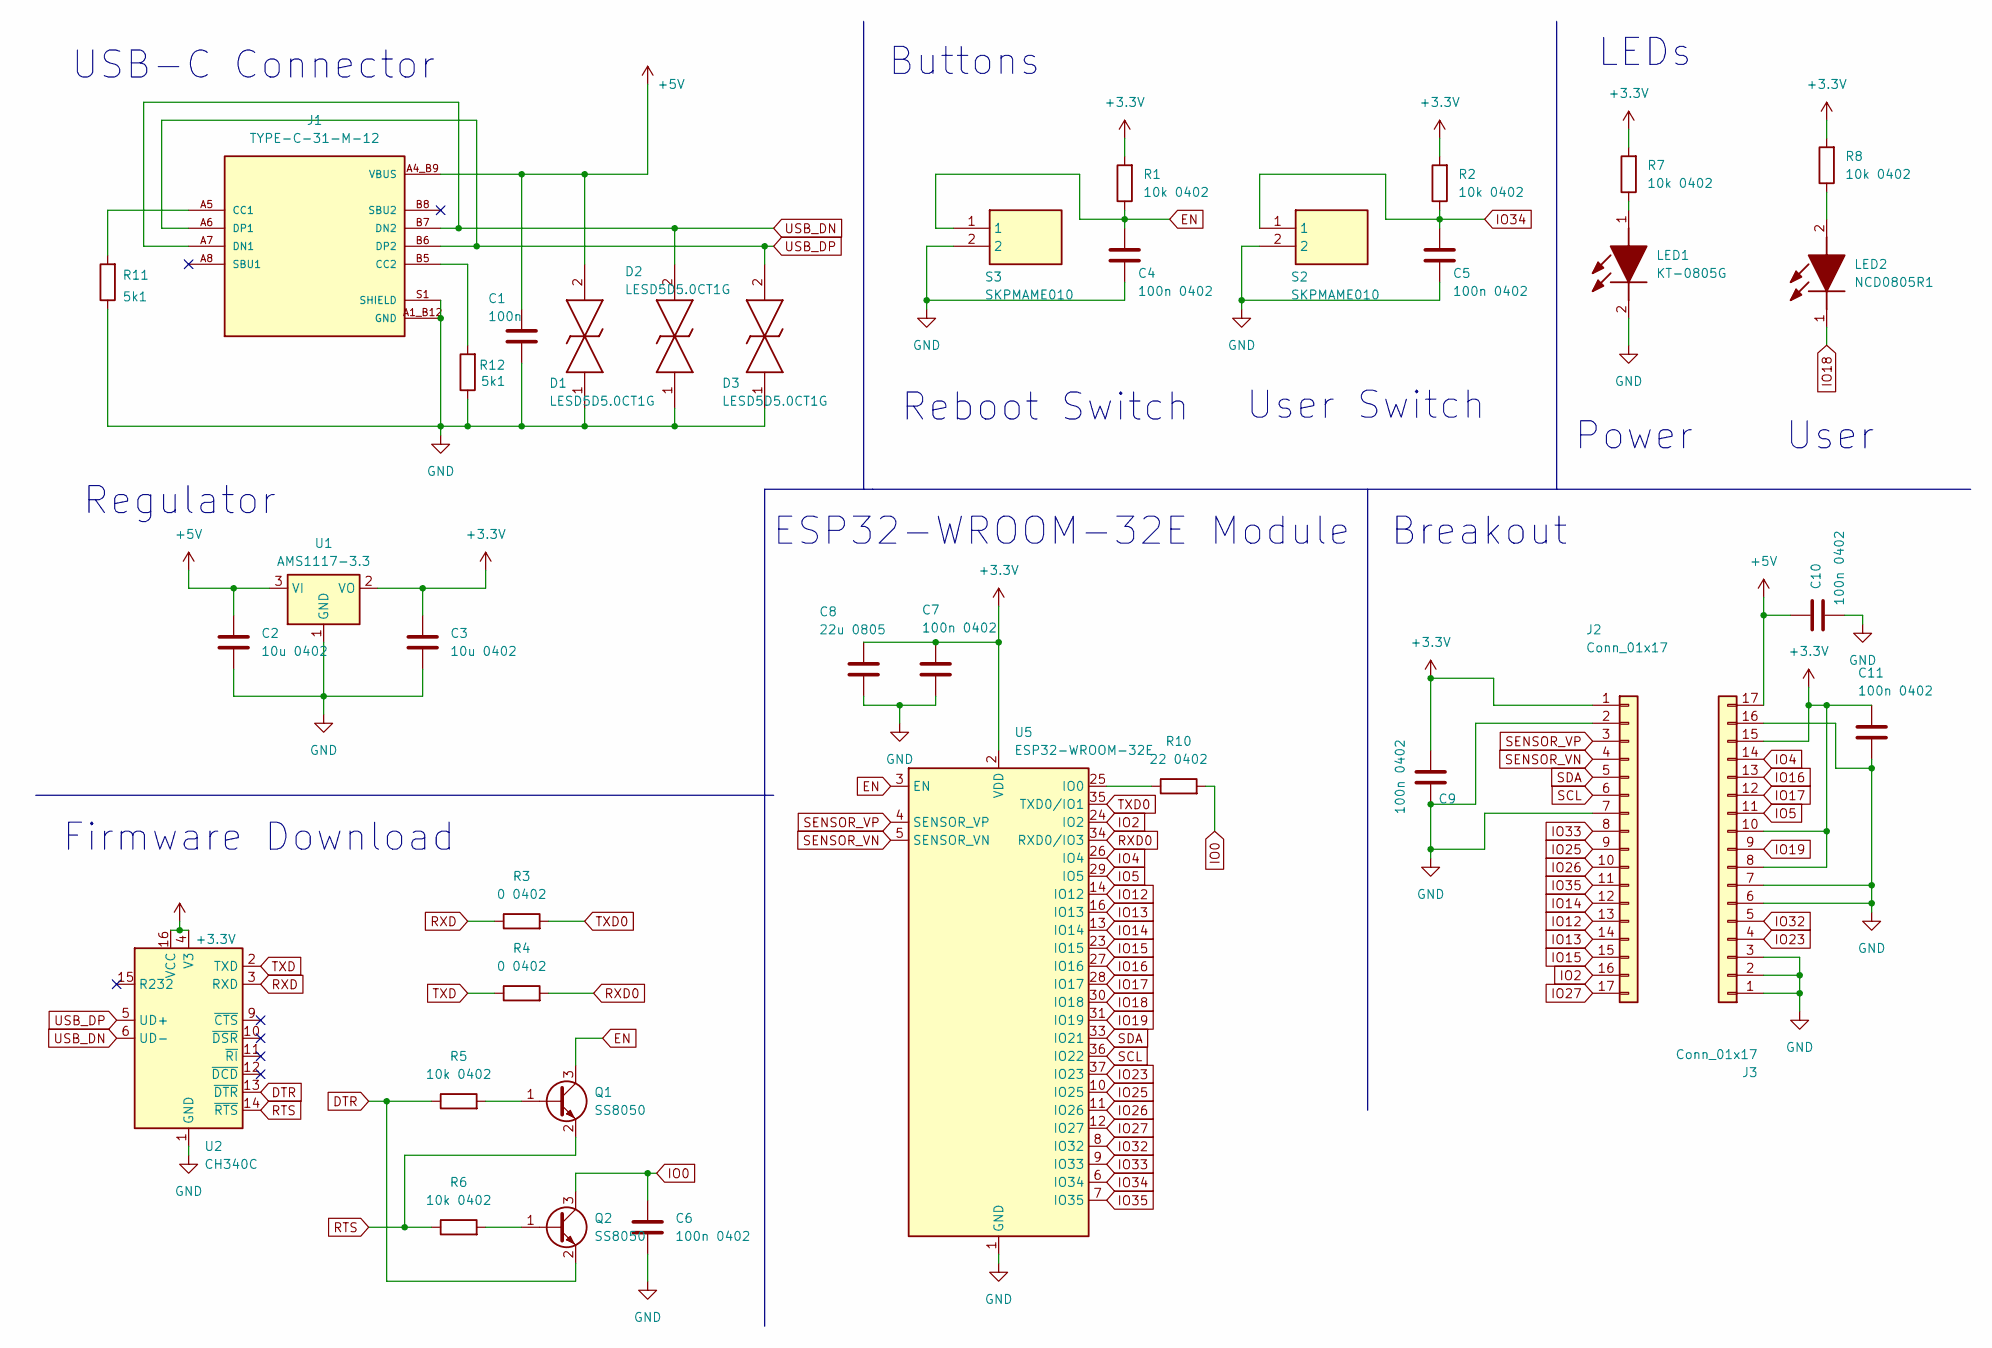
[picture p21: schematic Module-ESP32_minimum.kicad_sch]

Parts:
C1: 100n; C_0402_1005Metric
C2, C3: 10u 0402; C_0402_1005Metric
C4, C5, C6, C7, C9, C10, C11: 100n 0402; C_0402_1005Metric
C8: 22u 0805; C_0805_2012Metric
D1, D2, D3: LESD5D5.0CT1G; LESD5D50CT1G; Manufacturer_Part_Number LESD5D5.0CT1G
J1: TYPE-C-31-M-12; HRO_TYPE-C-31-M-12; PARTREV 2020.12.08
J2, J3: Conn_01x17; PinHeader_1x17_P1.27mm_Vertical
LED1: KT-0805G; KT0805G; Manufacturer_Part_Number KT-0805G
LED2: NCD0805R1; LEDC2012X120N; Manufacturer_Part_Number NCD0805R1
Q1, Q2: SS8050; SOT-23
R1, R2, R5, R6, R7, R8: 10k 0402; R_0402_1005Metric
R3, R4: 0 0402; R_0402_1005Metric
R10: 22 0402; R_0402_1005Metric
R11, R12: 5k1; R_0402_1005Metric
S2, S3: SKPMAME010; Manufacturer_Part_Number SKPMAME010; Mouser Part Number 688-SKPMAM
U1: AMS1117-3.3; SOT-223-3_TabPin2
U2: CH340C; STC_SOP-16_3.9x9.9mm_P1.27mm
U5: ESP32-WROOM-32E; ESP32-WROOM-32D

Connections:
+3.3V: C3.1, C7.1, C8.1, C9.1, C11.1, J2.1, J3.8, J3.10, J3.15, R1.2, R2.2, R7.2, R8.2, U1.2 (VO), U2.4 (V3), U2.16 (VCC), U5.2 (VDD)
+5V: C1.1, C2.1, C10.1, D1.2, J1.A4_B9 (VBUS), J1.B4_A9 (VBUS), J3.17, U1.3 (VI)
DTR: Q2.2 (E), R5.1, U2.13 (~DTR)
EN: C4.1, Q1.3 (C), R1.1, S3.1, U5.3 (EN)
GND: C1.2, C2.2, C3.2, C4.2, C5.2, C6.2, C7.2, C8.2, C9.2, C10.2, C11.2, D1.1, D2.1, D3.1, J1.A1_B12 (GND), J1.B1_A12 (GND), J1.S1 (SHIELD), J1.S2 (SHIELD), J1.S3 (SHIELD), J1.S4 (SHIELD), J2.2, J2.7, J3.1, J3.2, J3.3, J3.6, J3.7, J3.16, LED1.2 (K), R11.1, R12.1, S2.2, S3.2, U1.1 (GND), U2.1 (GND), U5.1 (GND), U5.15 (GND), U5.38 (GND), U5.39 (GND)
IO0: C6.1, Q2.3 (C), R10.2
IO2: J2.16, U5.24 (IO2)
IO4: J3.14, U5.26 (IO4)
IO5: J3.11, U5.29 (IO5)
IO12: J2.13, U5.14 (IO12)
IO13: J2.14, U5.16 (IO13)
IO14: J2.12, U5.13 (IO14)
IO15: J2.15, U5.23 (IO15)
IO16: J3.13, U5.27 (IO16)
IO17: J3.12, U5.28 (IO17)
IO18: LED2.1 (K), U5.30 (IO18)
IO19: J3.9, U5.31 (IO19)
IO23: J3.4, U5.37 (IO23)
IO25: J2.9, U5.10 (IO25)
IO26: J2.10, U5.11 (IO26)
IO27: J2.17, U5.12 (IO27)
IO32: J3.5, U5.8 (IO32)
IO33: J2.8, U5.9 (IO33)
IO34: C5.1, R2.1, S2.1, U5.6 (IO34)
IO35: J2.11, U5.7 (IO35)
unnamed: J1.A5 (CC1), R11.2
unnamed: J1.B5 (CC2), R12.2
unnamed: LED1.1 (A), R7.1
unnamed: LED2.2 (A), R8.1
unnamed: Q1.1 (B), R5.2
unnamed: Q2.1 (B), R6.2
unnamed: R10.1, U5.25 (IO0)
RTS: Q1.2 (E), R6.1, U2.14 (~RTS)
RXD: R3.1, U2.3 (RXD)
RXD0: R4.2, U5.34 (RXD0/IO3)
SCL: J2.6, U5.36 (IO22)
SDA: J2.5, U5.33 (IO21)
SENSOR_VN: J2.4, U5.5 (SENSOR_VN)
SENSOR_VP: J2.3, U5.4 (SENSOR_VP)
TXD: R4.1, U2.2 (TXD)
TXD0: R3.2, U5.35 (TXD0/IO1)
USB_DN: D2.2, J1.A7 (DN1), J1.B7 (DN2), U2.6 (UD-)
USB_DP: D3.2, J1.A6 (DP1), J1.B6 (DP2), U2.5 (UD+)

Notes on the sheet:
USB-C Connector
Power
User
Regulator
ESP32-WROOM-32E Module
User Switch
Buttons
Breakout
Reboot Switch
Firmware Download
LEDs

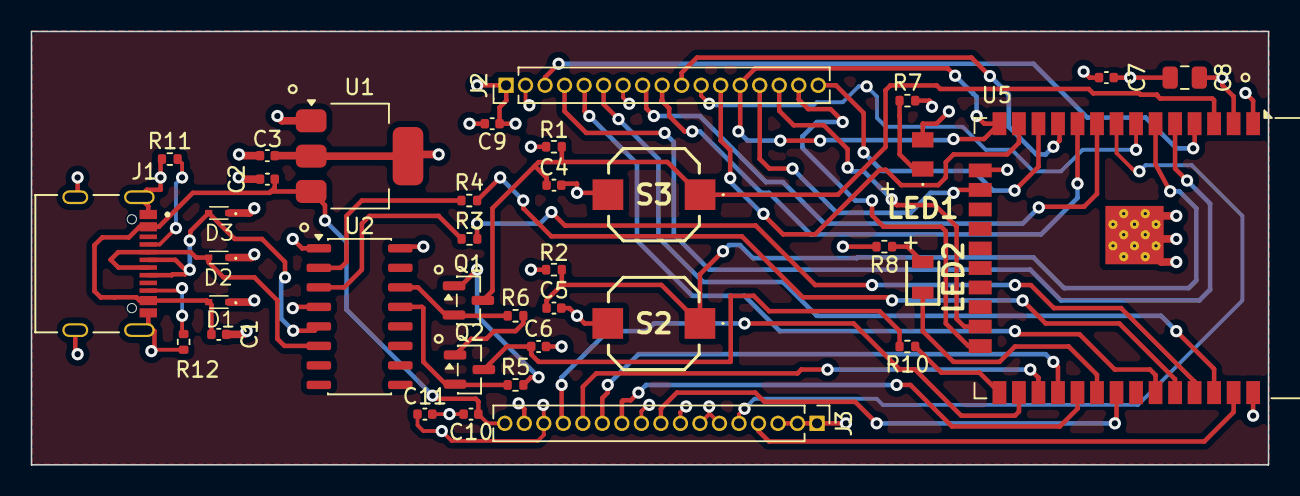
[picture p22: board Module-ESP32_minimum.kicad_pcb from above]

Board: 4 copper layers, 80.5 x 28.2 mm, 37 parts (0 on the bottom side), 43 nets.

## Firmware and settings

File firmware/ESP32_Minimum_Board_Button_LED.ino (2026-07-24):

/*
  ESP32-WROOM-32E Minimum Board
  User button -> User LED

  Schematic mapping:
    User switch (S2): GPIO34, external 10 kΩ pull-up to 3.3 V
                      pressed = LOW
    User LED (LED2): GPIO18, connected to 3.3 V through a resistor
                     GPIO18 LOW  = LED ON
                     GPIO18 HIGH = LED OFF

  Board target:
    ESP32 Dev Module / ESP32-WROOM-32E
*/

#include <Arduino.h>

constexpr gpio_num_t USER_BUTTON_PIN = GPIO_NUM_34;
constexpr gpio_num_t USER_LED_PIN    = GPIO_NUM_18;

constexpr uint32_t DEBOUNCE_MS = 30;

bool lastRawButtonState = HIGH;
bool stableButtonState  = HIGH;
uint32_t lastChangeTime = 0;

void setUserLed(bool on)
{
  // The LED is active-low because the GPIO sinks current.
  digitalWrite(USER_LED_PIN, on ? LOW : HIGH);
}

void setup()
{
  Serial.begin(115200);

  // GPIO34 has no internal pull-up/pull-down on the ESP32.
  // The schematic already provides an external 10 kΩ pull-up.
  pinMode(USER_BUTTON_PIN, INPUT);

  pinMode(USER_LED_PIN, OUTPUT);
  setUserLed(false);

  Serial.println();
  Serial.println("ESP32 board test started.");
  Serial.println("Press the USER switch to turn on the USER LED.");
}

void loop()
{
  const bool rawButtonState = digitalRead(USER_BUTTON_PIN);

  if (rawButtonState != lastRawButtonState)
  {
    lastRawButtonState = rawButtonState;
    lastChangeTime = millis();
  }

  if ((millis() - lastChangeTime) >= DEBOUNCE_MS &&
      stableButtonState != rawButtonState)
  {
    stableButtonState = rawButtonState;

    const bool buttonPressed = (stableButtonState == LOW);
    setUserLed(buttonPressed);

    Serial.println(buttonPressed ? "Button pressed: LED ON"
                                 : "Button released: LED OFF");
  }
}

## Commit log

2026-07-24 Rename 부품교체하는 방법.pptx to documents/부품교체하는 방법.pptx
2026-07-24 Rename 회로도 설명.docx to documents/회로도 설명.docx
